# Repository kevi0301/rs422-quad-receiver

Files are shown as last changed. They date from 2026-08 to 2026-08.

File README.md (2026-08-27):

# RS-422 Quad Receiver PCB
RS-422 Receiver PCB 3D View
4-channel RS-422 receiver PCB designed in KiCad with AC termination, TVS protection, test points, and fabrication outputs. 
## Features
- 4-channel RS-422 differential receiver
- AM26C32 receiver IC
- SM712 TVS protection for each input channel
- Configurable enable control with pull-up and pull-down resistors
- Power indicator with LED and 5V power input
- Local 0.1 uF decoupling capacitor
- Test points included in 5V, GND, and Y1-Y4 outputs
- 2-layer PCB with ground copper plane
- Mounting holes with copper keep-out areas
## PCB Design
- Designed and routed in KiCad
- Top and bottom copper routing
- Ground plane implemented on B.Cu
- DRC completed with 0 violations and 0 unrouted connections
- Silkscreen labeling added for debugging and board identification
## Fabrication
Gerber and Excellon PTH/NPTH drill files are included in the Fabrication folder.
## Project Status
PCB design and fabrication files complete. Physical fabrication and hardware validation have not yet been performed.

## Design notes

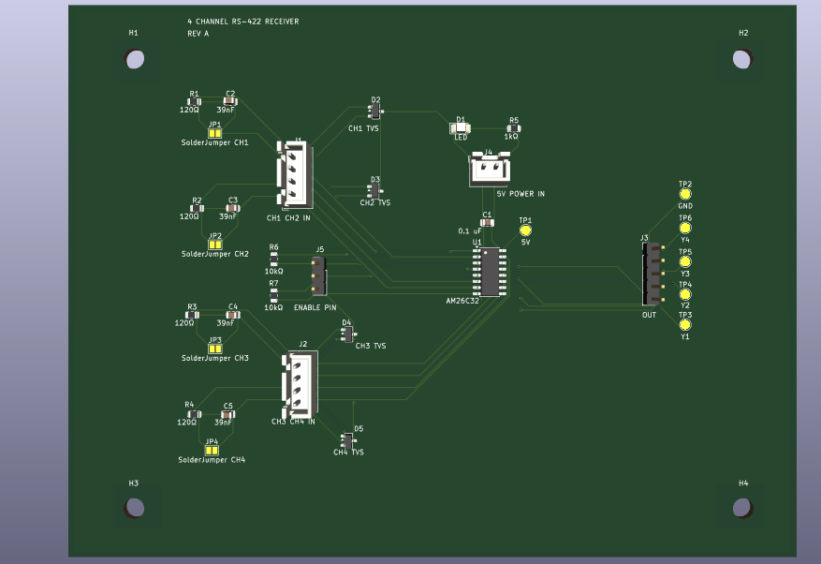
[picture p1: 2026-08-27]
rs-422 3d screenshot.png

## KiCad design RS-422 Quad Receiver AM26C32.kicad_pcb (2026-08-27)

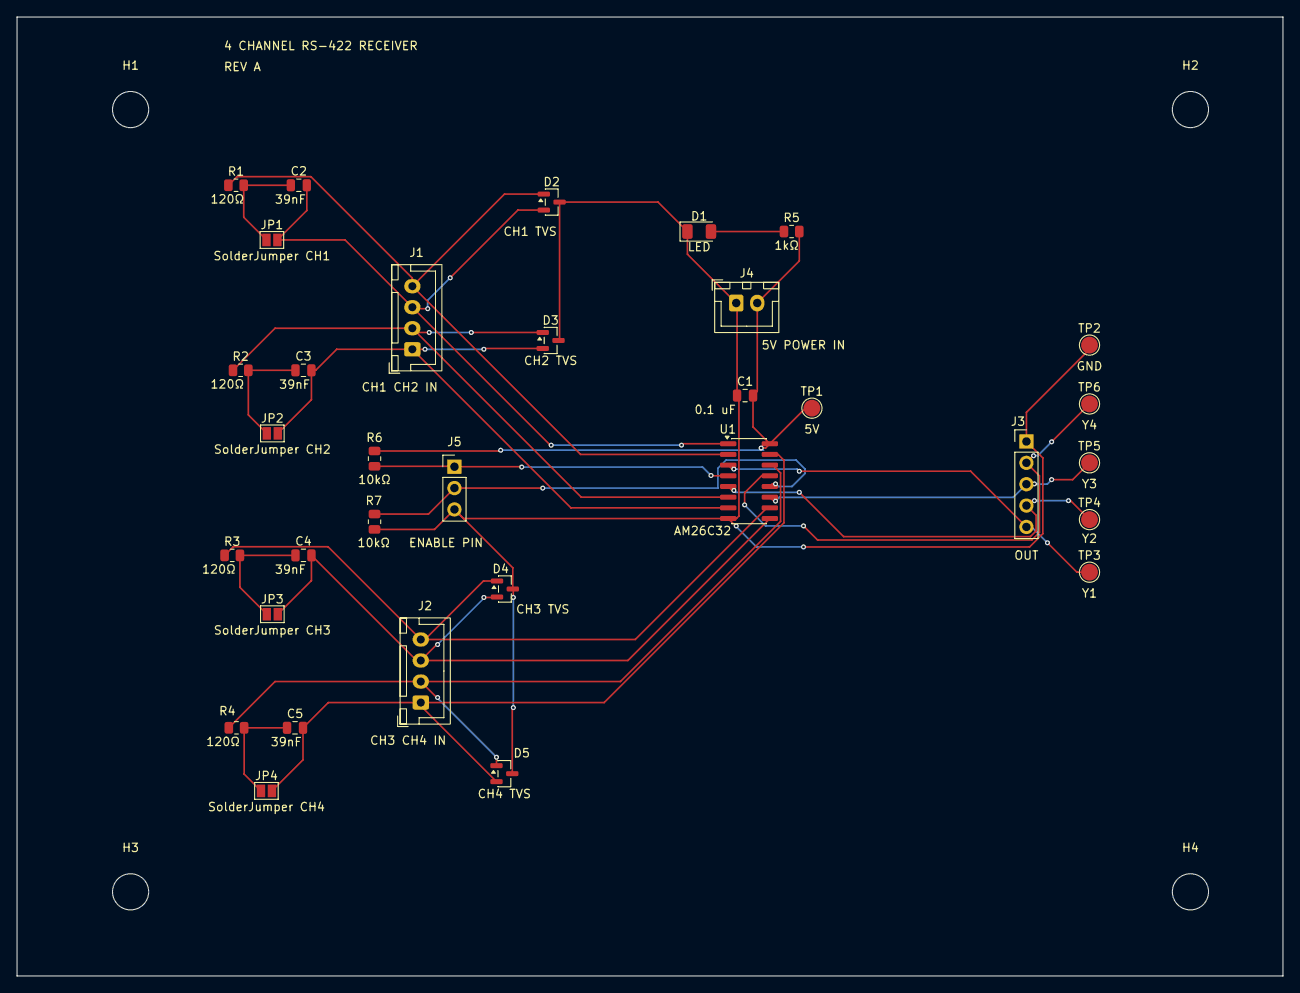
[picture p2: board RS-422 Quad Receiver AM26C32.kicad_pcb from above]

Board: 2 copper layers, 150.5 x 114.0 mm, 37 parts (0 on the bottom side), 21 nets.

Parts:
C1: 0.1 uF; C_0805_2012Metric
C2, C3, C4, C5: 39nF; C_0805_2012Metric
D1: LED; LED_1206_3216Metric
D2: CH1 TVS; SOT-23
D3: CH2 TVS; SOT-23
D4: CH3 TVS; SOT-23
D5: CH4 TVS; SOT-23
H1, H2, H3, H4: MountingHole; MountingHole_4.3mm_M4
J1: CH1 CH2 IN; JST_XH_B4B-XH-A_1x04_P2.50mm_Vertical
J2: CH3 CH4 IN; JST_XH_B4B-XH-A_1x04_P2.50mm_Vertical
J3: OUT; PinHeader_1x05_P2.54mm_Vertical
J4: 5V POWER IN; JST_XH_B2B-XH-A_1x02_P2.50mm_Vertical
J5: ENABLE PIN; PinHeader_1x03_P2.54mm_Vertical
JP1: SolderJumper CH1; SolderJumper-2_P1.3mm_Open_Pad1.0x1.5mm
JP2: SolderJumper CH2; SolderJumper-2_P1.3mm_Open_Pad1.0x1.5mm
JP3: SolderJumper CH3; SolderJumper-2_P1.3mm_Open_Pad1.0x1.5mm
JP4: SolderJumper CH4; SolderJumper-2_P1.3mm_Open_Pad1.0x1.5mm
R1, R2, R3, R4: 120Ω; R_0805_2012Metric
R5: 1kΩ; R_0805_2012Metric
R6, R7: 10kΩ; R_0805_2012Metric
TP1: 5V; TestPoint_Pad_D2.0mm
TP2: GND; TestPoint_Pad_D2.0mm
TP3: Y1; TestPoint_Pad_D2.0mm
TP4: Y2; TestPoint_Pad_D2.0mm
TP5: Y3; TestPoint_Pad_D2.0mm
TP6: Y4; TestPoint_Pad_D2.0mm
U1: AM26C32; SOIC-16_3.9x9.9mm_P1.27mm

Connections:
+5V: C1.2, J4.2, R5.2, R6.1, TP1.1 (1_1), U1.16 (VDD)
/1A: D2.1 (A1), J1.4, R1.1, U1.2 (1A)
/1B: C2.2, D2.2 (A2), J1.3, JP1.2 (B), U1.1 (1B)
/2A: D3.1 (A1), J1.2, R2.1, U1.6 (2A)
/2B: C3.2, D3.2 (A2), J1.1, JP2.2 (B), U1.7 (2B)
/3A: D4.1 (A1), J2.4, R3.1, U1.10 (3A)
/3B: C4.2, D4.2 (A2), J2.3, JP3.2 (B), U1.9 (3B)
/4A: D5.1 (A1), J2.2, R4.1, U1.14 (4A)
/4B: C5.2, D5.2 (A2), J2.1, JP4.2 (B), U1.15 (4B)
/G: J5.1, R6.2, U1.4 (G)
/Y1: J3.5, TP3.1 (1_1), U1.3 (1Y)
/Y2: J3.4, TP4.1 (1_1), U1.5 (2Y)
/Y3: J3.3, TP5.1 (1_1), U1.11 (3Y)
/Y4: J3.2, TP6.1 (1_1), U1.13 (4Y)
/Ḡ: J5.2, R7.1, U1.12 (~G)
GND: C1.1, D1.1 (K), D2.3 (common), D3.3 (common), D4.3 (common), D5.3 (common), J3.1, J4.1, J5.3, R7.2, TP2.1 (1_1), U1.8 (GND)
unnamed: D1.2 (A), R5.1
unnamed: C2.1, JP1.1 (A), R1.2
unnamed: C3.1, JP2.1 (A), R2.2
unnamed: C4.1, JP3.1 (A), R3.2
unnamed: C5.1, JP4.1 (A), R4.2

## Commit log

2026-08-27 Initial RS-422 receiver PCB project
    [RS-422 Quad Receiver AM26C32-B_Cu.gbr, RS-422 Quad Receiver AM26C32-B_Mask.gbr, RS-422 Quad Receiver AM26C32-B_Paste.gbr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]
2026-08-27 Add PCB 3D render
2026-08-27 Add 3D PCB image to README
